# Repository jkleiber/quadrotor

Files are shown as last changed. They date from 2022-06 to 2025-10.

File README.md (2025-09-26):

# Quadrotor

This is a project for the hardware and software of a quadcopter.

## Quadcopter 3D CAD
The quadcopter is 3D printed and all CAD work is done in OnShape in [this project](https://cad.onshape.com/documents/413384f17bd393d247c9b79e/w/f46ad751ac408daab1c55c23/e/428b8b34f12af24e5b48da17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)

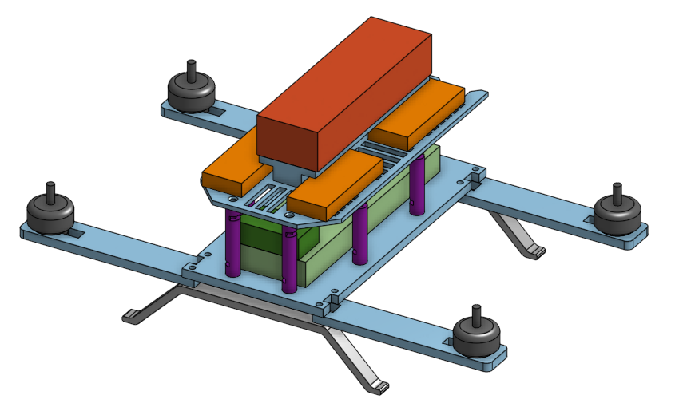
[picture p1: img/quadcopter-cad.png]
Quadcopter CAD


## Control Simulation GUI

The control simulator uses ImGui to allow for real-time data viewing and parameter tuning. Below is a snapshot of the GUI:

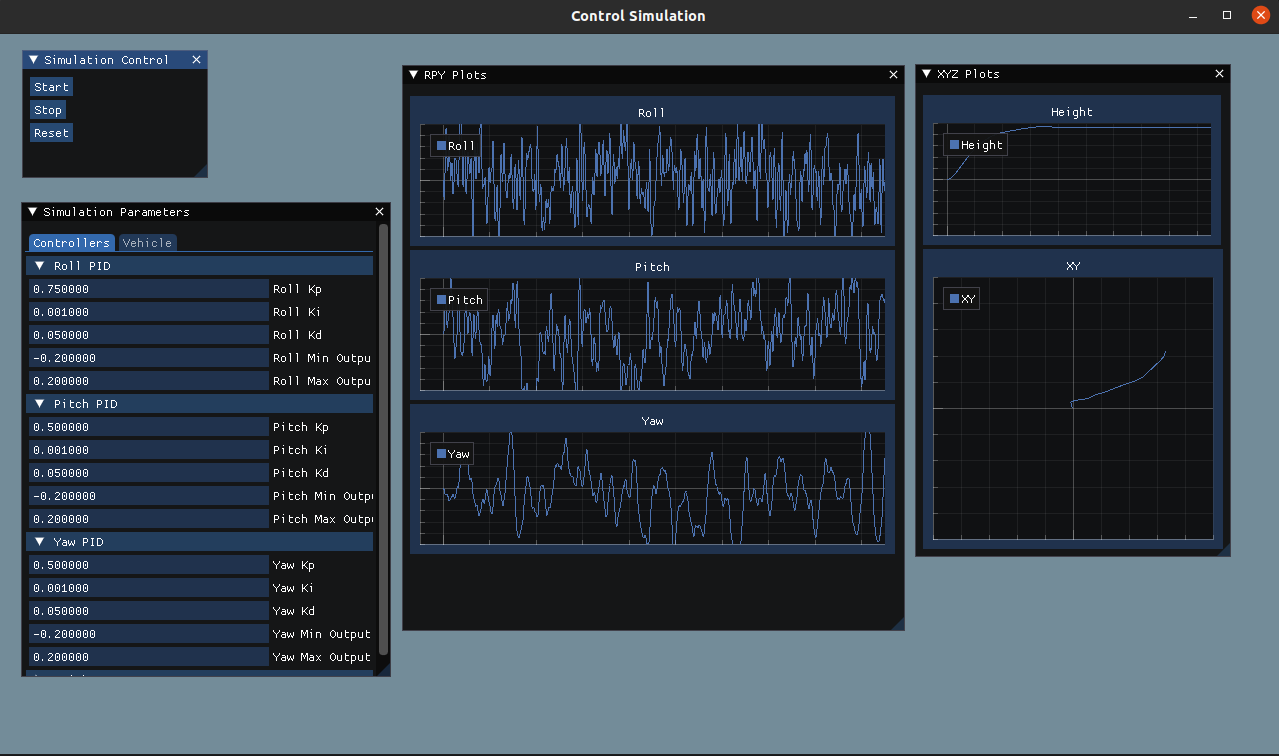
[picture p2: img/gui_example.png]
Control Sim GUI


## Hardware

A custom flight controller made in KiCAD exists in the `hardware/` directory. This is a breakout board for a Teensy, BNO055 IMU, a GPS module and the PWM outputs for the ESCs.

## Gazebo Simulation

There is a gazebo simulation environment in the `gazebo-sim/` directory. It is somewhat functional, but more work has been put into the control simulation GUI. The current gazebo settings aren't configured for the actual drone.

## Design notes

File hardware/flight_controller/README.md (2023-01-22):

# Flight Controller

## Development
The latest version is version 1.1. 

## Errata

### Version 1.1
- On both of the left motors, signal is labeled as ground and vice versa on the PWM output pins to the ESCs. Note made of this for future designs.

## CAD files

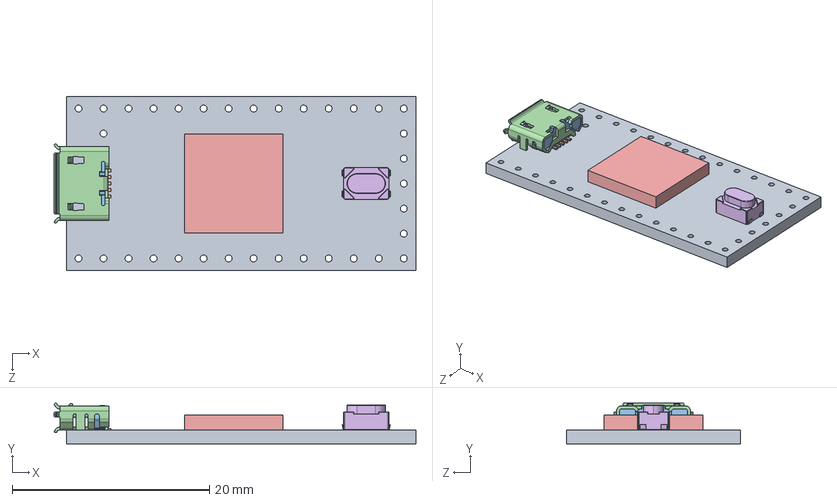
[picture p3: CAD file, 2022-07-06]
hardware/kicad_libraries/teensy.pretty-master/Teensy_4.0_Assembly.STEP
36.8 x 4.12 x 17.7 mm
Teensy_4.0_PCB
Micro USB-B Female 5Pin SMD
NXP iMXRT1062
SKRPACE010 v4

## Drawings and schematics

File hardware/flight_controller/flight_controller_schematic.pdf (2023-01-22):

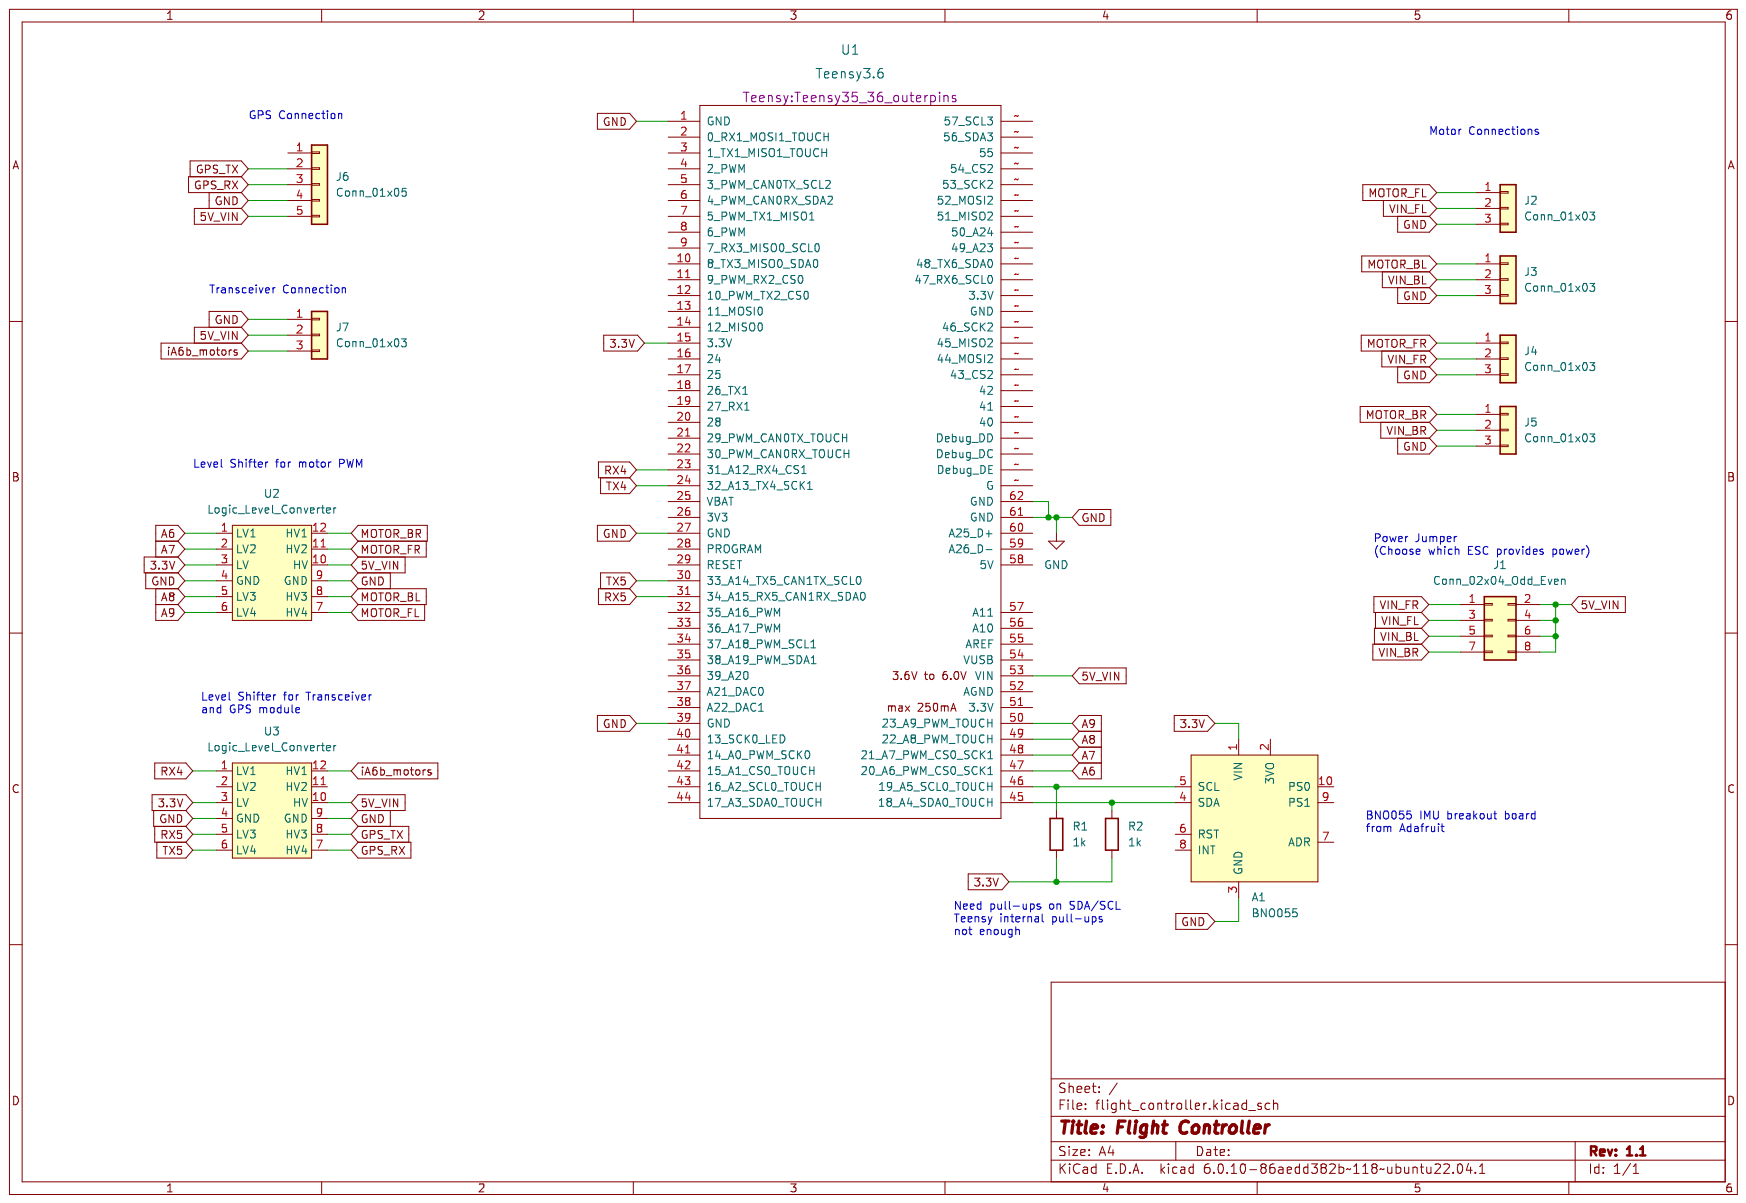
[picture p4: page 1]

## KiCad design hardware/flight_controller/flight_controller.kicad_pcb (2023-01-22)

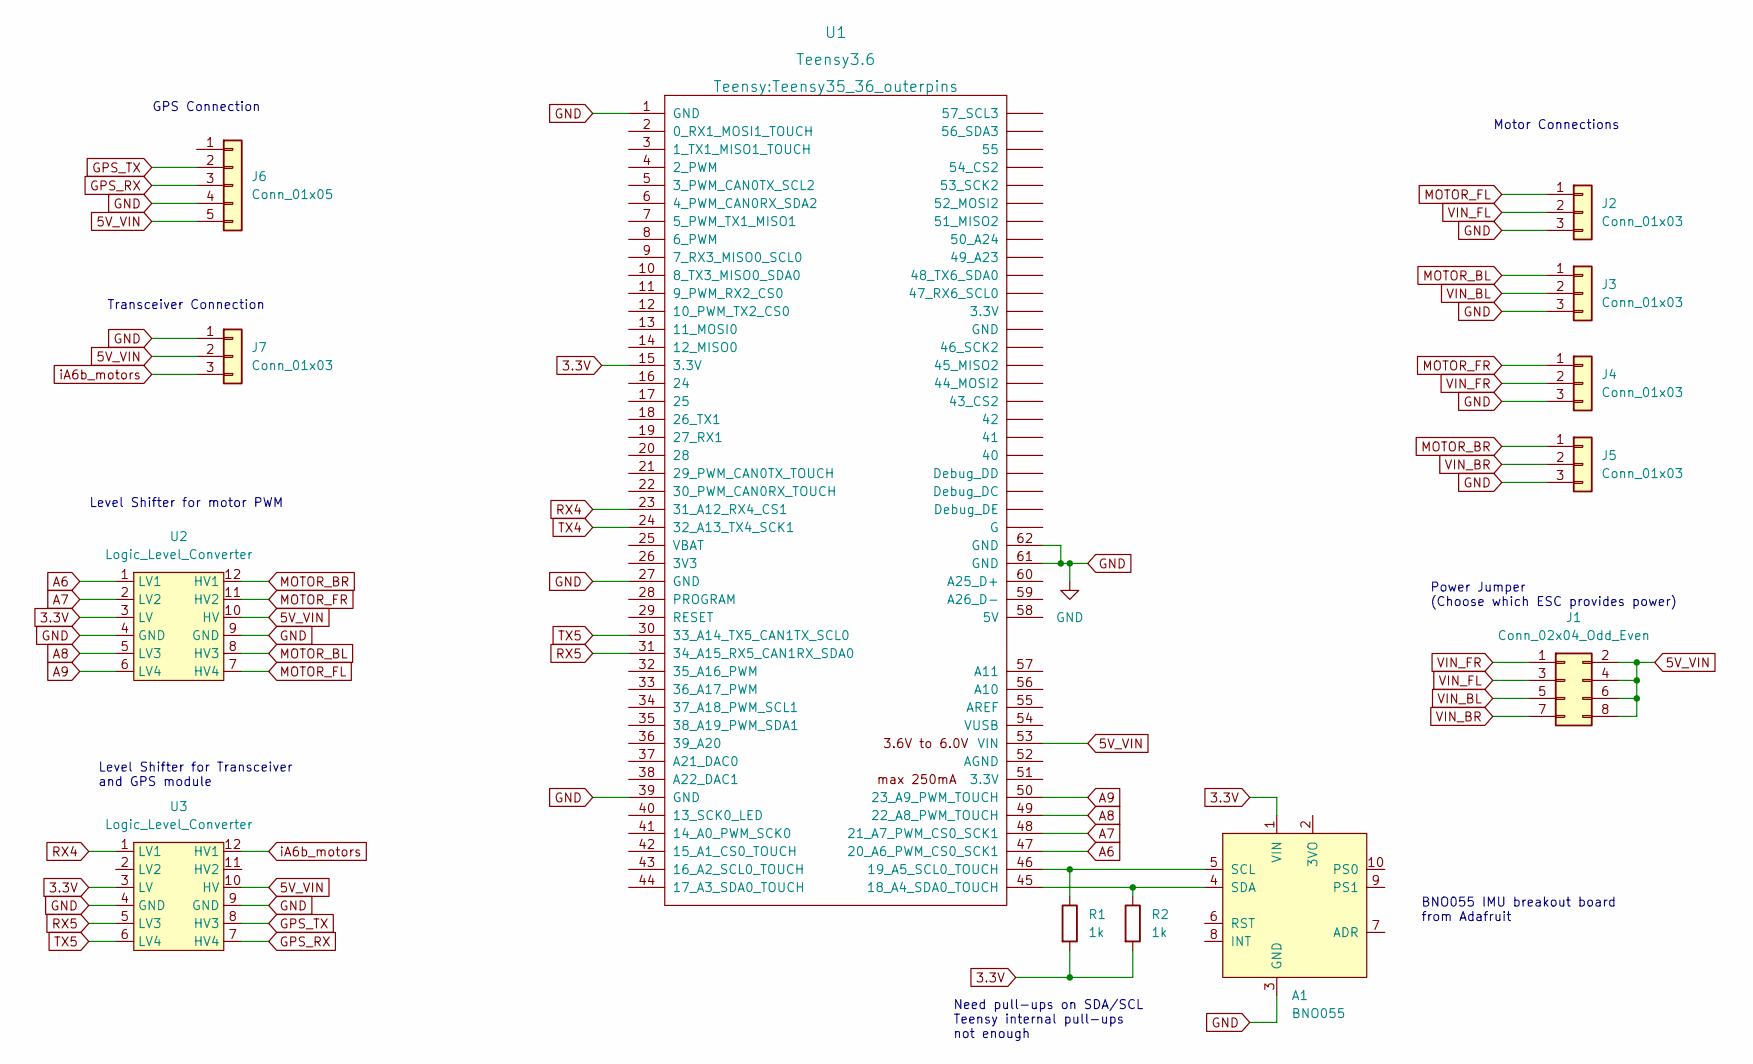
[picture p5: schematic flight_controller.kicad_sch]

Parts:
A1: BNO055
J1: Conn_02x04_Odd_Even; PinHeader_2x04_P2.54mm_Vertical
J2, J3, J4, J5: Conn_01x03; PinHeader_1x03_P2.54mm_Vertical
J6: Conn_01x05; PinSocket_1x05_P2.54mm_Vertical
J7: Conn_01x03; PinSocket_1x03_P2.54mm_Vertical
R1, R2: 1k; R_Axial_DIN0207_L6.3mm_D2.5mm_P15.24mm_Horizontal
U1: Teensy3.6; Teensy35_36_outerpins
U2, U3: Logic_Level_Converter

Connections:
3.3V: A1.1 (VIN), R1.2, R2.2, U1.15 (3.3V), U2.3 (LV), U3.3 (LV)
5V_VIN: J1.2, J1.4, J1.6, J1.8, J6.5, J7.2, U1.53 (VIN), U2.10 (HV), U3.10 (HV)
A6: U1.47 (20_A6_PWM_CS0_SCK1), U2.1 (LV1)
A7: U1.48 (21_A7_PWM_CS0_SCK1), U2.2 (LV2)
A8: U1.49 (22_A8_PWM_TOUCH), U2.5 (LV3)
A9: U1.50 (23_A9_PWM_TOUCH), U2.6 (LV4)
GND: A1.3 (GND), J2.3, J3.3, J4.3, J5.3, J6.4, J7.1, U1.1 (GND), U1.27 (GND), U1.39 (GND), U1.61 (GND), U1.62 (GND), U2.4 (GND), U2.9 (GND), U3.4 (GND), U3.9 (GND)
GPS_RX: J6.3, U3.7 (HV4)
GPS_TX: J6.2, U3.8 (HV3)
MOTOR_BL: J3.1, U2.8 (HV3)
MOTOR_BR: J5.1, U2.12 (HV1)
MOTOR_FL: J2.1, U2.7 (HV4)
MOTOR_FR: J4.1, U2.11 (HV2)
unnamed: A1.4 (SDA), R2.1, U1.45 (18_A4_SDA0_TOUCH)
unnamed: A1.5 (SCL), R1.1, U1.46 (19_A5_SCL0_TOUCH)
RX4: U1.23 (31_A12_RX4_CS1), U3.1 (LV1)
RX5: U1.31 (34_A15_RX5_CAN1RX_SDA0), U3.5 (LV3)
TX4: U1.24 (32_A13_TX4_SCK1)
TX5: U1.30 (33_A14_TX5_CAN1TX_SCL0), U3.6 (LV4)
VIN_BL: J1.5, J3.2
VIN_BR: J1.7, J5.2
VIN_FL: J1.3, J2.2
VIN_FR: J1.1, J4.2
iA6b_motors: J7.3, U3.12 (HV1)

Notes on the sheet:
Need pull-ups on SDA/SCL Teensy internal pull-ups not enough
Transceiver Connection
Level Shifter for motor PWM
Power Jumper (Choose which ESC provides power)
Level Shifter for Transceiver and GPS module
BNO055 IMU breakout board from Adafruit
Motor Connections
GPS Connection

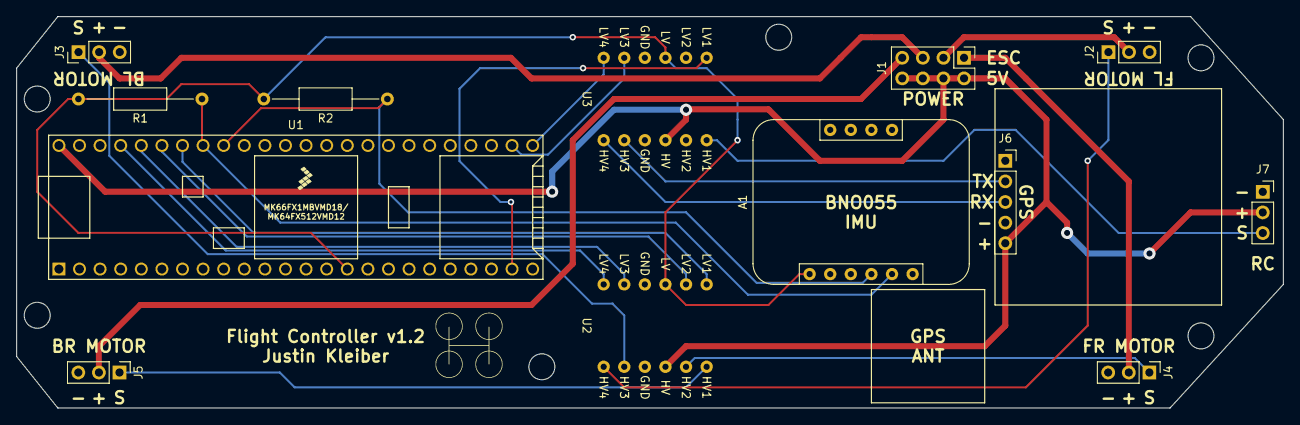
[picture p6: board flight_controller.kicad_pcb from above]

Board: 2 copper layers, 156.2 x 48.3 mm, 13 parts (0 on the bottom side), 23 nets.

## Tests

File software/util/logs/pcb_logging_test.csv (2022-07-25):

t | is_crashed | roll | pitch | yaw | throttle | roll_pid_out | pitch_pid_out | yaw_pid_out | motor_fl | motor_bl | motor_fr | motor_br | pwm_fl | pwm_bl | pwm_fr | pwm_br
6169 | 0 | 0.00 | -0.00 | 0.00 | -1.00 | -0.00 | 0.00 | 0.00 | 0.00 | 0.00 | 0.00 | 0.00 | 819 | 819 | 819 | 819
6177 | 0 | 0.00 | -0.00 | 0.00 | -1.00 | -0.03 | 0.04 | 0.00 | 0.00 | 0.00 | 0.00 | 0.00 | 819 | 819 | 819 | 819
6182 | 0 | 0.00 | -0.00 | 0.00 | -1.00 | -0.04 | 0.06 | 0.00 | 0.00 | 0.00 | 0.00 | 0.00 | 819 | 819 | 819 | 819
6188 | 0 | 0.00 | -0.00 | 0.00 | -1.00 | -0.04 | 0.05 | 0.00 | 0.00 | 0.00 | 0.00 | 0.00 | 819 | 819 | 819 | 819
6193 | 0 | 0.00 | -0.00 | 0.00 | -1.00 | -0.04 | 0.07 | 0.00 | 0.00 | 0.00 | 0.00 | 0.00 | 819 | 819 | 819 | 819
6199 | 0 | 0.00 | -0.00 | 0.00 | -1.00 | -0.04 | 0.05 | 0.00 | 0.00 | 0.00 | 0.00 | 0.00 | 819 | 819 | 819 | 819
6206 | 0 | 0.00 | -0.00 | 0.00 | -1.00 | -0.03 | 0.05 | 0.00 | 0.00 | 0.00 | 0.00 | 0.00 | 819 | 819 | 819 | 819
6211 | 0 | 0.00 | -0.00 | 0.00 | -1.00 | -0.04 | 0.06 | 0.00 | 0.00 | 0.00 | 0.00 | 0.00 | 819 | 819 | 819 | 819
6217 | 0 | 0.00 | -0.00 | 0.00 | -1.00 | -0.04 | 0.06 | 0.00 | 0.00 | 0.00 | 0.00 | 0.00 | 819 | 819 | 819 | 819
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

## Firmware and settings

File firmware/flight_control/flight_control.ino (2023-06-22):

// Copyright (C) 2023 Justin Kleiber

#include <Adafruit_BNO055.h>
#include <Adafruit_Sensor.h>
#include <IBusBM.h>
#include <SD.h>
#include <SPI.h>
#include <Wire.h>
#include <utility/imumaths.h>

#include "attitude_control.h"
#include "constants.h"
#include "control_utils.h"
#include "lpf.h"
#include "pid.h"
#include "pwm_utils.h"

float deg_to_rad(float deg) { return deg * PI / 180.0; }
float rad_to_deg(float rad) { return rad * 180.0 / PI; }

// IBus Interface
IBusBM ibus;

// Remote control values
int channel_values[6];

// SD card settings
// Note: this only works on Teensy 3.6, and the SD logging depends on the Teensy
// version of the SD library.
const int kSDChipSelect = BUILTIN_SDCARD;

// Logging
char log_base_name[] = "flight_\0";
char log_file_name[LOG_FN_LEN] = {'\0'};
int flight_num = 0;
String log_headers =
    "t,is_crashed,roll,pitch,yaw,p,q,r,throttle,p_cmd,q_cmd,r_cmd,roll_cmd,"
    "pitch_cmd,yaw_cmd,roll_pid_out,pitch_pid_out,yaw_pid_out,motor_fl,motor_"
    "bl,motor_fr,motor_br,pwm_fl,pwm_bl,pwm_fr,pwm_br";
bool is_logging_available = false;
const int kLogPrecision = 6;

// Debugging
bool is_rc_debug = false;
bool is_imu_debug = false;
bool is_pid_debug = false;
bool is_scope_debug = false;
bool is_pwm_debug = false;

// Crash detection
bool is_crashed = false;

// BNO055 IMU
Adafruit_BNO055 bno = Adafruit_BNO055(69, 0x28);

// Motor trim
// NOTE: this needs to be tuned after ESC calibration
// TODO: make this a config file or controlled by the RC
float fl_trim = 0.0;
float fr_trim = 0.00;
float bl_trim = 0.04;
float br_trim = 0.04;

// Control System
AttitudeControl attitude_ctrl;
AttitudeControlOutputs attitude_out;

// Filter constants
const float kGyroMix = 0.95;

// States
// Angles (rad)
float roll = 0.0;
float pitch = 0.0;
float yaw = 0.0;
// Angular rates (rad/s)
float roll_rate = 0.0;
float pitch_rate = 0.0;
float yaw_rate = 0.0;

// State filters
const float kAngleLpfMix = 1;
LowPassFilter roll_lpf(roll, kAngleLpfMix);
LowPassFilter pitch_lpf(pitch, kAngleLpfMix);
LowPassFilter yaw_lpf(yaw, kAngleLpfMix);

const float kRateLpfMix = 1;
LowPassFilter p_lpf(roll_rate, kRateLpfMix);
LowPassFilter q_lpf(pitch_rate, kRateLpfMix);
LowPassFilter r_lpf(yaw_rate, kRateLpfMix);

// Calibration
bool is_calibrated = false;

// Calibration offsets
float roll_offset = 0.0;  // deg
float pitch_offset = 0.0; // deg

// Control setpoints
float roll_setpoint = 0.0;  // deg
float pitch_setpoint = 0.0; // deg
float yaw_setpoint = 0.0;   // deg
float p_setpoint = 0.0;     // deg/s
float q_setpoint = 0.0;     // deg/s
float r_setpoint = 0.0;     // deg/s

// Numerical derivative for rates
unsigned long t_prev = millis();
float roll_prev = 0.0;  // deg
float pitch_prev = 0.0; // deg

// Motor power
float front_left_out = 0.0;
float back_left_out = 0.0;
float front_right_out = 0.0;
float back_right_out = 0.0;

// Motor PWMs
int pwm_fl = 0;
int pwm_bl = 0;
int pwm_fr = 0;
int pwm_br = 0;

// Find yaw to be an angle offset relative to the yaw setpoint
// This is to maintain transitioning from the simulator until the
// PID controller is re-implemented better.
float augment_yaw(float yaw_setpoint, float yaw)
{
    // Assumptions:
    // 1. Yaw is in [0, 360)
    // 2. Yaw setpoint can be in (-inf, inf)
    // 3. Both yaw and yaw setpoint are in degrees

    // Convert yaw setpoint to be in [0, 360)
    float setpoint_0_360 = fmod(yaw_setpoint, 360);
    if (setpoint_0_360 < 0.0)
    {
        setpoint_0_360 += 360;
    }

    // Two ways of going around a circle.
    float delta_1 = 0.0;
    float delta_2 = 0.0;

    // Find the two differences if yaw setpoint is larger than yaw
    if (setpoint_0_360 > yaw)
    {
        // Direct path
        delta_1 = -1.0 * (setpoint_0_360 - yaw);
        // Going around the wrap-around point
        delta_2 = (360 - setpoint_0_360) + yaw;

        // flip the direction
        if (abs(delta_2) < abs(delta_1))
        {
            delta_1 = delta_2;
        }
    }
    else
    {
        // Direct path
        delta_1 = yaw - setpoint_0_360;
        // Going around the wrap-around point
        delta_2 = (360 - yaw) + setpoint_0_360;

        // flip the direction if the second way is shorter
        if (abs(delta_2) < abs(delta_1))
        {
            delta_1 = -1.0 * delta_2;
        }
    }

    // Set the output yaw to be in the neighborhood of the setpoint
    float yaw_out = yaw_setpoint + delta_1;

    return yaw_out;
}

int get_flight_number()
{
    int i = 1;
    while (i <= 1000000)
    {
        // Convert the number to a string
        char buf[12];
        itoa(i, buf, 10);

        // Make the name based on the other log files
        char name[20] = {'\0'};
        Serial.print(name);
        Serial.print("\t");
        strcat(name, log_base_name);
        strcat(name, buf);
        Serial.print("Checking: ");
        Serial.println(name);

        // If the name isn't taken, then set it.
        // Also, only allow logging if a file name exists
        if (!SD.exists(name))
        {
            return i;
        }

        // Increment counter and try again.
        i++;
    }

    // Error if there is no flight number
    return -1;
}

void setup()
{
    // Set up USB Serial for debugging
    Serial.begin(115200);

    if (!bno.begin())
    {
        // There was a problem detecting the BNO055.
        Serial.print("No BNO055 detected - aborting flight control");
        while (1)
            ;
    }

    // If the SD card is inserted, enable logging to the SD card.
    if (SD.begin(kSDChipSelect))
    {
        // Name the file
        flight_num = get_flight_number();

        if (flight_num >= 0)
        {
            // Logging is available
            is_logging_available = true;

            // Stringify the flight number
            char flight_str_buf[12];
            itoa(flight_num, flight_str_buf, 10); // 10 = base-10

            // Form the log filename
            strcat(log_file_name, log_base_name);
            strcat(log_file_name, flight_str_buf);

            // const char* version of the log filename
            const char *logfile = const_cast<const char *>(log_file_name);

            // Set logging headers
            File log_file = SD.open(logfile, FILE_WRITE);
            log_file.println(log_headers);
            log_file.close();
        }
        Serial.print("Logging enabled! Log file: ");
        Serial.println(log_file_name);
    }
    else
    {
        Serial.println("SD Card failed to load! Logging is not enabled.");
    }

    // Set up the IBusBM Serial interface.
    // Use IBUSBM_NOTIMER to run the loop ourselves.
    // Timing in IBusBM is not supported on Teensy 3.6.
    ibus.begin(Serial4, IBUSBM_NOTIMER);

    // Configure the motor ports to be outputs.
    pinMode(kFrontLeftMotor, OUTPUT);
    pinMode(kBackLeftMotor, OUTPUT);
    pinMode(kFrontRightMotor, OUTPUT);
    pinMode(kBackRightMotor, OUTPUT);

    // Set the PWM resolution
    analogWriteResolution(kPwmResolution);

    // Set the PWM frequencies for each motor to 50 Hz.
    analogWriteFrequency(kFrontLeftMotor, 50);
    analogWriteFrequency(kBackLeftMotor, 50);
    analogWriteFrequency(kFrontRightMotor, 50);
    analogWriteFrequency(kBackRightMotor, 50);

    // Initialize the controllers.
    attitude_ctrl.Init();

    // Init the prev time to the start time.
    t_prev = micros();

    // Wait for BNO055 to initialize
    delay(5000);
}

void loop()
{

    // Run the IBusBM loop here since the interrupt
    // timing is not supported on Teensy 3.6.
    ibus.loop();

    // Read remote control channels
    for (int i = 0; i < 6; i++)
    {
        channel_values[i] = ibus.readChannel(i);

        if (is_rc_debug)
        {
            Serial.print(i);
            Serial.print(": ");
            Serial.print(channel_values[i]);
            Serial.print(" ");
        }
    }

    // Print a new line for debugging.
    if (is_rc_debug)
    {
        Serial.println();
    }

    // Get a sensor event from the BNO055 for orientation.
    sensors_event_t rpy_event;
    bno.getEvent(&rpy_event, Adafruit_BNO055::VECTOR_EULER);

    // Get a sensor event from the BNO055 for angular velocity.
    sensors_event_t pqr_event;
    bno.getEvent(&pqr_event, Adafruit_BNO055::VECTOR_GYROSCOPE);

    // Set the roll, pitch and yaw. The offsets start at 0, but then are
    // calibrated once on startup. Note: this depends on the orientation of the
    // BNO055 in the quadcopter itself. Modify as needed to achieve the correct
    // orientation.
    float roll_input = rpy_event.orientation.z - roll_offset;
    float pitch_input = (-1.0 * rpy_event.orientation.y) - pitch_offset;

    // Lowpass filter the angles
    roll = roll_lpf.Filter(roll_input);
    pitch = pitch_lpf.Filter(pitch_input);

    // Compute yaw as the closest angle to the yaw setpoint
    // This also converts yaw to radians
    float yaw_input = rpy_event.orientation.x;
    yaw = yaw_lpf.Filter(yaw_input);
    yaw = augment_yaw(yaw_setpoint, yaw);

    // Compute the roll and pitch rate numerically
    float dt = (float)(millis() - t_prev) / 1000.0;
    roll_rate = (float)(roll - roll_prev) / dt;
    pitch_rate = (float)(pitch - pitch_prev) / dt;

    // Set current values as previous
    t_prev = millis();
    roll_prev = roll;
    pitch_prev = pitch;

    // Set the angular rates in rad/s. Complementary filter between the
    // numerical derivative and the gyro values.
    float roll_rate_input =
        (1.0 - kGyroMix) * roll_rate + kGyroMix * rad_to_deg(pqr_event.gyro.z);
    float pitch_rate_input = (1.0 - kGyroMix) * pitch_rate +
                             kGyroMix * rad_to_deg(-1.0 * pqr_event.gyro.y);
    float yaw_rate_input =
        (1.0 - kGyroMix) * yaw_rate + kGyroMix * rad_to_deg(pqr_event.gyro.x);

    // Lowpass filter angular rates
    roll_rate = p_lpf.Filter(roll_rate_input);
    pitch_rate = q_lpf.Filter(pitch_rate_input);
    yaw_rate = r_lpf.Filter(yaw_rate_input);

    if (is_imu_debug)
    {
        Serial.print("Roll: ");
        Serial.print(roll);
        Serial.print(" Pitch: ");
        Serial.print(pitch);
        Serial.print(" Yaw: ");
        Serial.println(yaw);
    }

    // Convert the rc throttle input to a motor power percentage
    float throttle =
        convert_rc_throttle_to_power(channel_values[kThrottleChannel]);

    // The quadcopter is crashed if it rolls or pitches too much.
    if (fabs(roll) >= kRollLimit || fabs(pitch) >= kPitchLimit)
    {
        is_crashed = true;

        // Reset the PIDs.
        attitude_ctrl.Reset();
    }

    // The quadcopter can only be un-crashed once the throttle is set low and
    // the quadcopter is upright
    if (throttle < kThrottleCutoff && fabs(roll) < kRollLimit &&
        fabs(pitch) < kPitchLimit)
    {
        is_crashed = false;
    }

    // Get remote control inputs.
    float roll_stick =
        convert_rc_stick_to_range(channel_values[kRollChannel], 0.0, 1.0);
    float pitch_stick =
        convert_rc_stick_to_range(channel_values[kPitchChannel], 0.0, 1.0);
    float yaw_stick = 0.5;

    // Package all control system inputs.
    AttitudeControlInputs inputs = {roll_rate,  pitch_rate,  yaw_rate,
                                    roll,       pitch,       yaw,
                                    roll_stick, pitch_stick, yaw_stick};

    // Run control loops.
    attitude_ctrl.Process(inputs, &attitude_out);

    // Unpack output for motors and logging.
    float roll_output = attitude_out.roll_output;
    float pitch_output = attitude_out.pitch_output;
    float yaw_output = attitude_out.yaw_output;
    p_setpoint = attitude_out.p_setpoint;
    q_setpoint = attitude_out.q_setpoint;
    r_setpoint = attitude_out.r_setpoint;
    roll_setpoint = attitude_out.roll_setpoint;
    pitch_setpoint = attitude_out.pitch_setpoint;
    yaw_setpoint = attitude_out.yaw_setpoint;

    // If the quadcopter hasn't been calibrated, then set the roll and pitch
    // offsets. This runs at the start before flying. Only do this if the
    // quadcopter is reasonably level (within +/- 5 degrees). Otherwise the
    // calibration should not occur (fly with 0 roll/pitch offset).
    if (!is_calibrated && fabs(roll) < kMaxStableRoll &&
        fabs(pitch) < kMaxStablePitch)
    {
        // These offsets are in radians.
        roll_offset = roll;
        pitch_offset = pitch;

        // Calibration is set
        is_calibrated = true;
    }
    else if (!is_calibrated)
    {
        // Choose to keep the 0 degree offset in order to take off from uneven
        // surfaces.
        is_calibrated = true;
    }
    else if (throttle >= kThrottleCutoff && !is_crashed && is_calibrated)
    {
        // Don't do anything unless the throttle is outside a deadband, and the
        // quadcopter is uncrashed. The IMU positions must also be calibrated.

        // Enforce a minimum throttle, but scale cubically
        float throttle_above_cutoff = (throttle - kThrottleCutoff);
        throttle = (throttle_above_cutoff * throttle_above_cutoff *
                    throttle_above_cutoff) +
                   kMinThrottle;
        Clamp(&throttle, kMinThrottle, 1.0);

        // MOTOR MAPPING
        // Compute power for each motor.
        front_left_out =
            throttle - roll_output + pitch_output + yaw_output + fl_trim;
        back_left_out =
            throttle - roll_output - pitch_output - yaw_output + bl_trim;
        front_right_out =
            throttle + roll_output + pitch_output - yaw_output + fr_trim;
        back_right_out =
            throttle + roll_output - pitch_output + yaw_output + br_trim;

        // Apply trim and convert power to PWM
        pwm_fl = convert_power_to_pwm(front_left_out);
        pwm_bl = convert_power_to_pwm(back_left_out);
        pwm_fr = convert_power_to_pwm(front_right_out);
        pwm_br = convert_power_to_pwm(back_right_out);

        // Clamp the duty cycles
        pwm_fl = clamp_pwm_duty(pwm_fl, kPwmMinDutyMicros, kPwmMaxDutyMicros);
        pwm_bl = clamp_pwm_duty(pwm_bl, kPwmMinDutyMicros, kPwmMaxDutyMicros);
        pwm_fr = clamp_pwm_duty(pwm_fr, kPwmMinDutyMicros, kPwmMaxDutyMicros);
        pwm_br = clamp_pwm_duty(pwm_br, kPwmMinDutyMicros, kPwmMaxDutyMicros);

        if (is_pid_debug)
        {
            Serial.print("FL: ");
            Serial.print(front_left_out);
            Serial.print(" BL: ");
            Serial.print(back_left_out);
            Serial.print(" FR: ");
            Serial.print(front_right_out);
            Serial.print(" BR: ");
            Serial.println(back_right_out);
        }
    }
    // Otherwise output the idle (motors off) duty cycle.
    else
    {
        front_left_out = 0.0;
        back_left_out = 0.0;
        front_right_out = 0.0;
        back_right_out = 0.0;

        pwm_fl = kIdlePwm;
        pwm_bl = kIdlePwm;
        pwm_fr = kIdlePwm;
        pwm_br = kIdlePwm;

        // Reset the PIDs
        attitude_ctrl.Reset();
    }

    if (is_pwm_debug)
    {
        Serial.print("FL: ");
        Serial.print(pwm_fl);
        Serial.print(" BL: ");
        Serial.print(pwm_bl);
        Serial.print(" FR: ");
        Serial.print(pwm_fr);
        Serial.print(" BR: ");
        Serial.println(pwm_br);
    }

    // Motor outputs
    analogWrite(kFrontLeftMotor, pwm_fl);
    analogWrite(kBackLeftMotor, pwm_bl);
    analogWrite(kFrontRightMotor, pwm_fr);
    analogWrite(kBackRightMotor, pwm_br);

    if (is_scope_debug)
    {
        int scope_input = analogRead(kScopePin);
        Serial.println(scope_input);
    }

    // Logging
    if (is_logging_available)
    {
        // const char* version of the log filename
        const char *logfile = const_cast<const char *>(log_file_name);

        // Create a data string
        String data = String(millis()) + "," + String(is_crashed) + "," +
                      String(roll, kLogPrecision) + "," +
                      String(pitch, kLogPrecision) + "," +
                      String(yaw, kLogPrecision);
        data += "," + String(roll_rate) + "," + String(pitch_rate) + "," +
                String(yaw_rate, kLogPrecision);
        data += "," + String(throttle, kLogPrecision) + "," +
                String(p_setpoint, kLogPrecision) + "," +
                String(q_setpoint, kLogPrecision) + "," +
                String(r_setpoint, kLogPrecision) + "," +
                String(roll_setpoint, kLogPrecision) + "," +
                String(pitch_setpoint, kLogPrecision) + "," +
                String(yaw_setpoint, kLogPrecision);
        data += "," + String(roll_output, kLogPrecision) + "," +
                String(pitch_output, kLogPrecision) + "," +
                String(yaw_output, kLogPrecision);
        data += "," + String(front_left_out, kLogPrecision) + "," +
                String(back_left_out, kLogPrecision) + "," +
                String(front_right_out, kLogPrecision) + "," +
                String(back_right_out, kLogPrecision);
        data += "," + String(pwm_fl) + "," + String(pwm_bl) + "," +
                String(pwm_fr) + "," + String(pwm_br);

        // Open the file, write a new line and then close.
        File log_file = SD.open(logfile, FILE_WRITE);
        log_file.println(data);
        log_file.close();
    }

    // Target 500 Hz, expect 100 Hz
    delay(2);
}

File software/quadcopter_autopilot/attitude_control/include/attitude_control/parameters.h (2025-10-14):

#ifndef ATTITUDE_CONTROL_PARAMETERS_H_
#define ATTITUDE_CONTROL_PARAMETERS_H_

enum ControlMode
{
    Rate = 0,
    Angle = 1
};
const ControlMode kMode = Rate;

// Crash detection
const float kRollLimit = 110.0;  // deg
const float kPitchLimit = 110.0; // deg

// Calibration
const float kMaxStableRoll = 5.0;  // deg
const float kMaxStablePitch = 5.0; // deg

// Scope Pin
// const int kScopePin = A14;

// Motor PWM pins
const int kFrontLeftMotor = 23;
const int kBackLeftMotor = 22;
const int kFrontRightMotor = 21;
const int kBackRightMotor = 20;

// RC channels (0-indexed)
const int kThrottleChannel = 2; // This is Channel 3 when 1-indexed
const int kPitchChannel = 1;
const int kRollChannel = 0;

// Remote control deadbands
// Throttle cutoff
// Note: This is equivalent to ~1020 us input on the RC.
const float kThrottleCutoff = 0.1f; // Motor power 10%

// Command limits
const float kMaxRollCmd = 20.0;  // deg
const float kMaxPitchCmd = 20.0; // deg

const float kMaxRollRateCmd = 200.0;  // deg
const float kMaxPitchRateCmd = 200.0; // deg
const float kMaxYawRateCmd = 100.0;   // deg

// PID Gains
// Roll
const float kRollKp = 0.05;
const float kRollKi = 0.00001;
const float kRollKd = 0.001;
const float kRollLeak = 0.99;
// Pitch
const float kPitchKp = 0.07;
const float kPitchKi = 0.0001;
const float kPitchKd = 0.001;
const float kPitchLeak = 0.99;
// Yaw
const float kYawKp = 0.06;
const float kYawKi = 0.0001;
const float kYawKd = 0.001;
const float kYawLeak = 0.99;

// Roll Rate
const float kRollRatePDRatio = 40;
const float kRollRateKp = -0.001;
const float kRollRateKi = -0.00000001;
const float kRollRateKd = kRollRateKp / kRollRatePDRatio;
const float kRollRateKf = -0.0001;
const float kRollRateLeak = 0.99;
const float kRollRateIntegralLimit = 0.1 / kRollRateKi;
// Pitch Rate
const float kPitchRatePDRatio = 2 * 10;
const float kPitchRateKp = 0.0006;
const float kPitchRateKi = 0.00000001;
const float kPitchRateKd = kPitchRateKp / kPitchRatePDRatio;
const float kPitchRateKf = 0.0001;
const float kPitchRateLeak = 0.99;
const float kPitchRateIntegralLimit = 0.1 / kPitchRateKi;
// Yaw Rate
const float kYawRatePDRatio = 2 * 10;
const float kYawRateKp = 0.0006;
const float kYawRateKi = 0.00000001;
const float kYawRateKd = kYawRateKp / kYawRatePDRatio;
const float kYawRateKf = 0.0001;
const float kYawRateLeak = 0.99;
const float kYawRateIntegralLimit = 0.1 / kYawRateKi;

// PID output limits
// Inner loop (rate) PID limits
const float kRatePIDLower = -0.25; // %
const float kRatePIDUpper = 0.25;  // %

// Angular rate deadband
const float kRateDeadband = 10.0; // (deg/s)

// Throttle curve parameters
const float kMinThrottle = 0.22;

#endif

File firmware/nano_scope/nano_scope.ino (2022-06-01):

const int scope_pin = 2;

const int trigger = 500; // square wave trigger
volatile unsigned long last_low = 0;
volatile unsigned long last_high = 0;
bool is_high = false;
float frequency = 0;

volatile int down_time = 0;
volatile int up_time = 0;

volatile int signal_val = 1;

void scope_trigger()
{
  signal_val = digitalRead(scope_pin);

  if(signal_val == HIGH)
  {
    down_time = millis() - last_high;
    last_low = millis();
  }
  else
  {
    up_time = millis() - last_low;
    last_high = millis();
  }
}



void setup() {
  // put your setup code here, to run once:
  pinMode(scope_pin, INPUT_PULLUP);

  Serial.begin(115200);

  // Frequency trackers
  last_low = millis();
  last_high = millis();

  attachInterrupt(digitalPinToInterrupt(scope_pin), scope_trigger, CHANGE);
  
}

void loop() {
  Serial.print("Uptime:");
  Serial.print(up_time);
  Serial.print(",");
  Serial.print("DownTime:");
  Serial.print(down_time);
  Serial.print(",");
  Serial.print("Signal:");
  Serial.println(signal_val);
//  int val = 100*digitalRead(scope_pin);
//  
//
//  // Track frequency
//  if (val == HIGH && !is_high)
//  {
//    // Compute frequency
//    frequency = 1.0 / ((float)(millis() - last_low) / 1000.0);
//    
//    is_high = true;
//    last_low = millis();
//  }
//  else if(val == LOW && is_high)
//  {
//    // Compute frequency
////    frequency = 1.0 / ((float)(millis() - last_high) / 1000.0);
//
//    is_high = false;
//    last_high = millis();
//  }
//
//  Serial.print("Signal:");
//  Serial.print(val);
//  Serial.print(",");
//  Serial.print("Freq:");
//  Serial.println(frequency);
  
  delay(1);
}

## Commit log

2021-08-26 Creates project workflow scripts, makes quadcopter plugin work in gazebo, makes a really bad bang-bang controller for the drone that keeps it at the right height as long as the drone is set up perfec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
    [quadrotor-blocks.sdf]
2022-05-30 Begins work on quadcopter firmware, starting with the interface between the FS-iA6b receiver and the Teensy 3.6 using IBusBM
2022-06-01 Initial calibration, testing and flight control.
    Flight control is a disaster at the moment. Need to probably make a model and try to control that
2022-06-12 Begins to work on simulating the control system for the quadcopter. Makes a safety mode for the quadcopter to avoid crashes causing more damage than they should
    [control_loop.cpp, flight_control.ino]
2022-06-14 Creates a height PID that does decently well at stabilizing the drone's height. About 0.15m ss error
    [control_loop.cpp]
2022-06-19 Adds logging and data analysis tool for simulation. Also creates initial PID attitude control that works in sim. Need to smooth out the control signal and add a delay to the motor throttle dynamics t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
2022-06-21 Adds slew rate limit and makes PID controllers less aggressive
2022-07-03 Adds SD logging to flight control firmware, but will only be able to test when the FC is rewired/PCB is ordered due to space issues
    [flight_control.ino]
2022-07-06 Begins PCB project for flight controller
    [Teensy_4.0_Assembly.STEP, flight_controller.kicad_pcb, flight_controller.kicad_sch]
2022-07-09 PCB design for flight controller is basically complete. Need to verify and have fun with the design before ordering
    [flight_controller.kicad_pcb, flight_controller.kicad_sch]
2022-07-09 Finalizes and orders flight controller PCB
    [flight_controller-B_Cu.gbr, flight_controller-B_Mask.gbr, flight_controller-B_Paste.gbr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]
2022-07-11 Design v1 sent to JLC PCB
    [flight_controller.kicad_pcb]
2022-07-23 Updates FC board to v1.1 due to footprint size error
    Need to choose different parts and include BOM for hardware
    [flight_controller.kicad_pcb]
2022-07-25 Fixes PCB for v1.1, gets logging working in firmawre, adds data viewing in jupyter notebooks
    [flight_controller-B_Cu.gbr, flight_controller-B_Mask.gbr, flight_controller-B_Paste.gbr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]
2022-07-28 Orders PCB, fixes IMU polarity for roll in the firmware after testing
    [flight_control.ino]
2022-07-28 Saves PCB design
2022-07-29 Adds PID control display tools
2023-01-22 Wired up the quadcopter with v1.1 and tried to fly it. Control loops still need tuning, but auto-stop works
    Begins updated v1.2 PCB (just errata of v1.1 for now) and need to improve simulation with initial system ID
    Weighed drone and it weighs 1 kg (1001 g)
    [flight_controller.kicad_pcb]
2023-03-25 PID gain tuning, but the front right motor is getting hot and might be a problem
    [flight_controller.kicad_sch]
2023-04-01 More filtering and better analysis
2023-04-02 Switching back to rate mode to see if this can fly. It looks like the rate PIDs are actually too slow
    [flight_control.ino]
2023-04-04 Converts everything to degrees, also makes utils for PWM
2023-04-07 More PID tuning... The frame may need to be re-thought to get better performance
2023-04-20 Found bug in angular rate measurement logic, switching to pypoetry for notebooks
    [flight_control.ino]
2023-06-22 Optimized throttle curve
2023-06-24 Thrust testing only, attitude control is disabled
2025-09-26 refactors simulation into gazebo-sim
    [quadrotor-blocks.sdf]
2025-09-28 Makes the simulator camera track the quadcopter
    next up: actually simulate quadcopter motion
2025-09-28 reorganizes script and analysis file structure
    [pcb_logging_test.csv]
2025-10-14 Begins migrating autopilot from arduino to C++ to allow for sim on real software
